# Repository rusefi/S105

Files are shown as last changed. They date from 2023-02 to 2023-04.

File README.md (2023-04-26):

# S105

Reverse engineering of SOATE S105 396200-3763010-00 ECU using KiCad EDA

[TL,DR: schematics (see open issues)](hardware/s105/s105.pdf)

[Interactive Pinout](https://rusefi.com/docs/pinouts/s105/)

Geehy apm32F407VGT7

[Forum Discussion](https://rusefi.com/forum/viewtopic.php?f=4&t=2496)

x



https://www.youtube.com/watch?v=v7S3eSeuTio

Alternative unofficial firmware https://github.com/rusefi/rusefi/tree/master/firmware/config/boards/s105

Binary https://rusefi.com/build_server/rusefi_bundle_s105.zip

See also https://github.com/rusefi/m74.9

[rusefi-status.md](rusefi-status.md)

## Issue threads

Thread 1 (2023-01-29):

источники

rusefillc, 2023-01-29:
В проекте уже есть две маленькие подсхемы https://github.com/rusefi/S105/tree/main/hardware/s105

Главный разъём предлагаю взять из районов https://github.com/rusefi/hellen121vag - на S105 на самом деле 81 пиновая варианция, но мы проигнорируем это различие. @Nadezhda-n подключу библиотеку, какую скажешь.

распиновка главного разъёма https://rusefi.com/docs/pinouts/s105/

100pin stm32 символ и типичная обвязка вокруг https://github.com/rusefi/hw_microRusEfi/

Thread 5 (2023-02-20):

VR

rusefillc, 2023-02-20:
VR A1 требует уточнения. Q19, наверно, диодная сборка. А R247-251 и R252-253 требует уточнения подключения

Nadezhda-n, 2023-02-21:
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
Одно уточнение, действительно, появилось

rusefillc, 2023-05-01:
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

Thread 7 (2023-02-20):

OD 2A14

rusefillc, 2023-02-20:
Схема OD 2A14 требует уточнения. Не подключен силовой транзистор. Непонятно как он управляется. Предположительно перепутана полярность маленьких диодов. Контакт разъема 13  это не выход, а вход.

Nadezhda-n, 2023-02-21:
Честно говоря, я не следила за полярностью маленьких диодов - мне не очень видно :)

Nadezhda-n, 2023-02-21:
> Схема OD 2A14 требует уточнения. Не подключен силовой транзистор. Непонятно как он управляется. Предположительно перепутана полярность маленьких диодов. Контакт разъема 13 это не выход, а вход.

Если ты про D15, то я и прозвонкой не нашла, и дорожки от него не видно, и отверстия нет (на другой стороне), так что я тут даже и не знаю...

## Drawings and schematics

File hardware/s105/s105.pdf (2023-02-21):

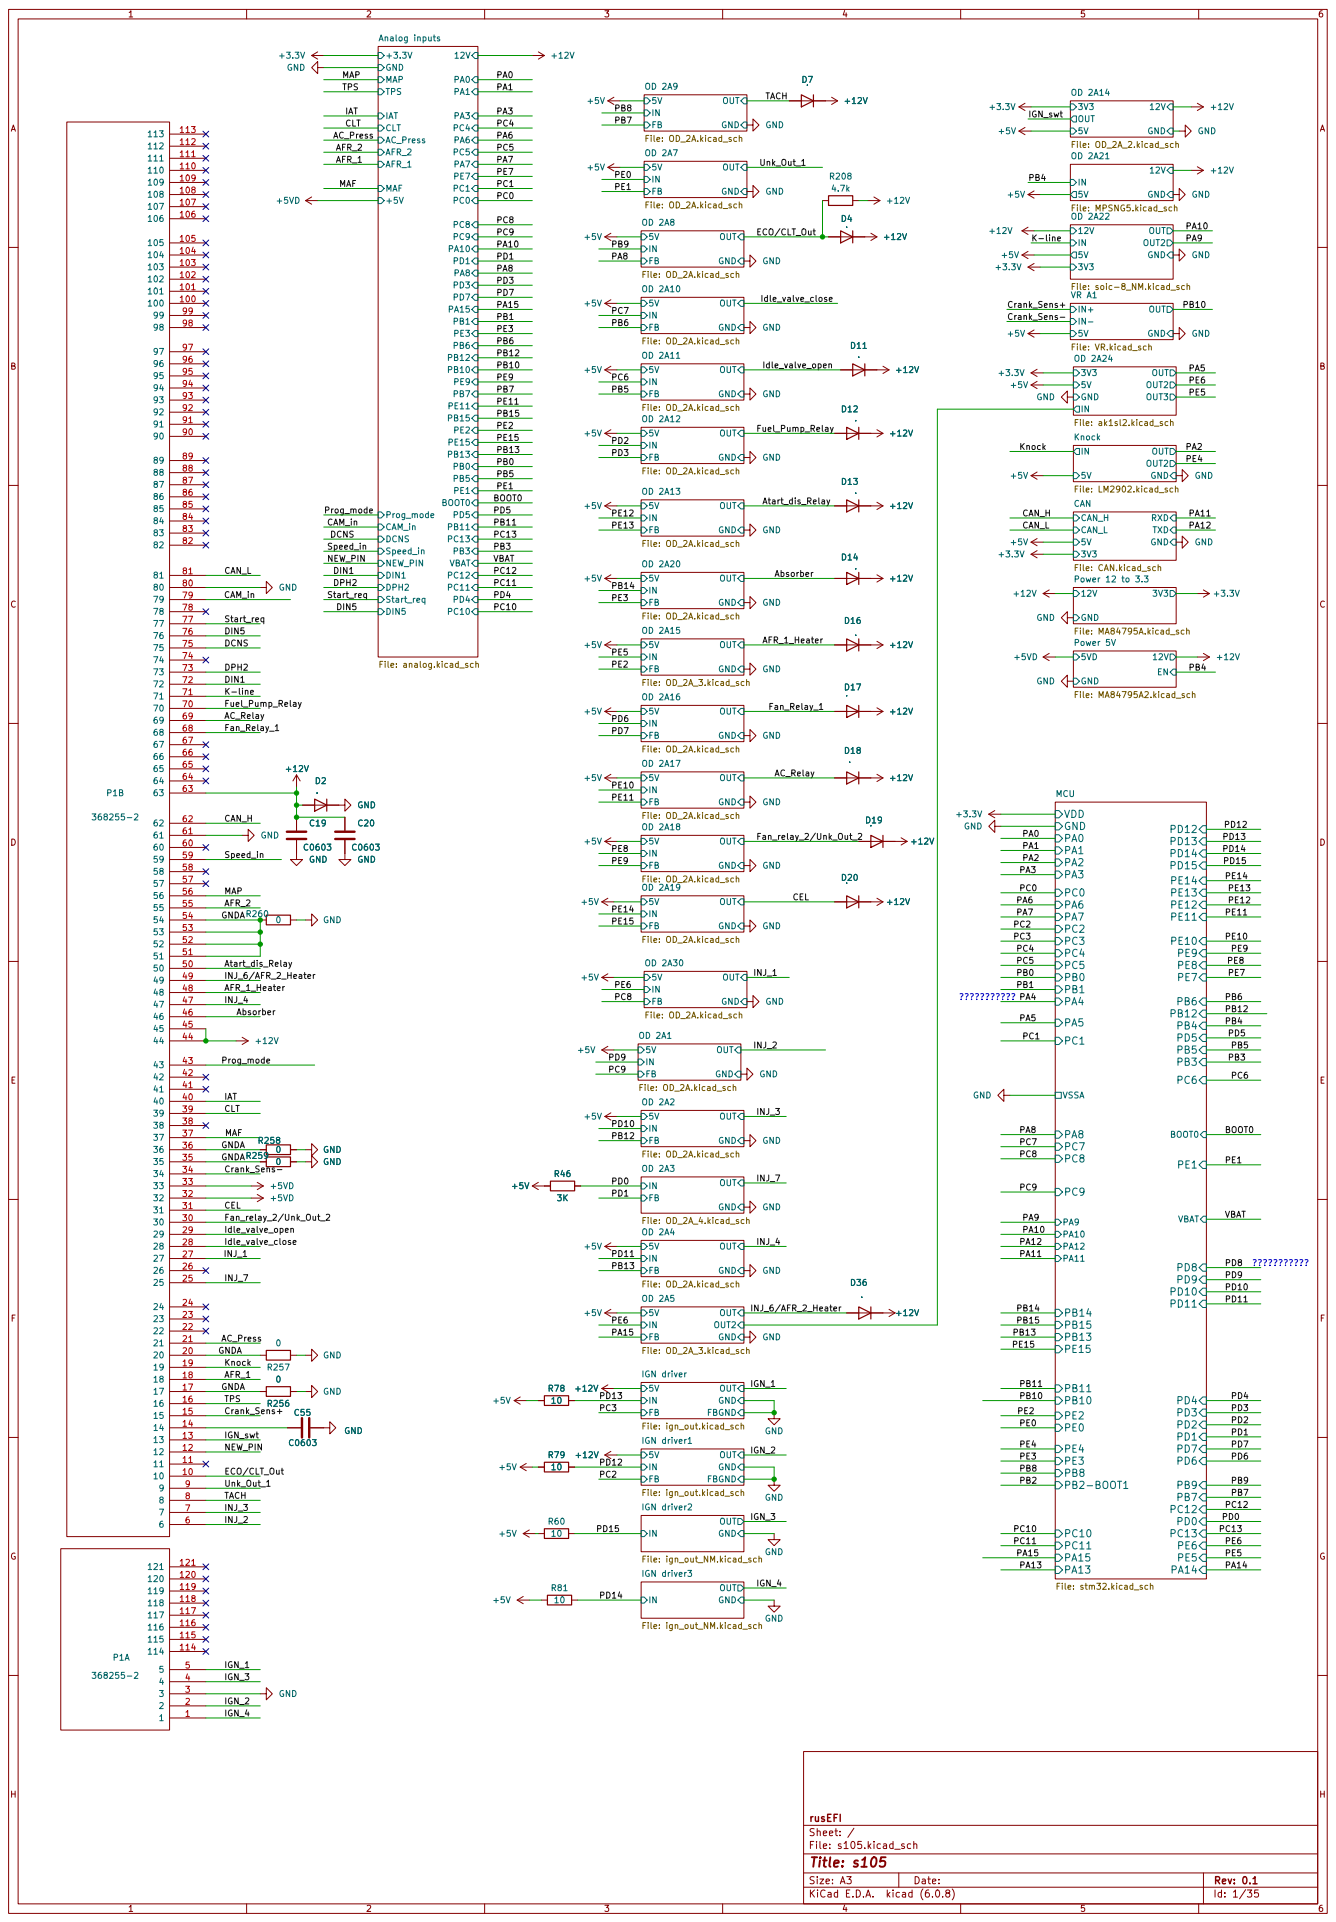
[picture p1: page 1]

3V3 OD 2A22 File: soic-8_NM.kicad_sch OUT

IN- VR A1 File: VR.kicad_sch

3V3 Power 12 to 3.3 File: MA84795A.kicad_sch OUT
GND

File: s105.kicad_sch Sheet: / rusEFI OUT

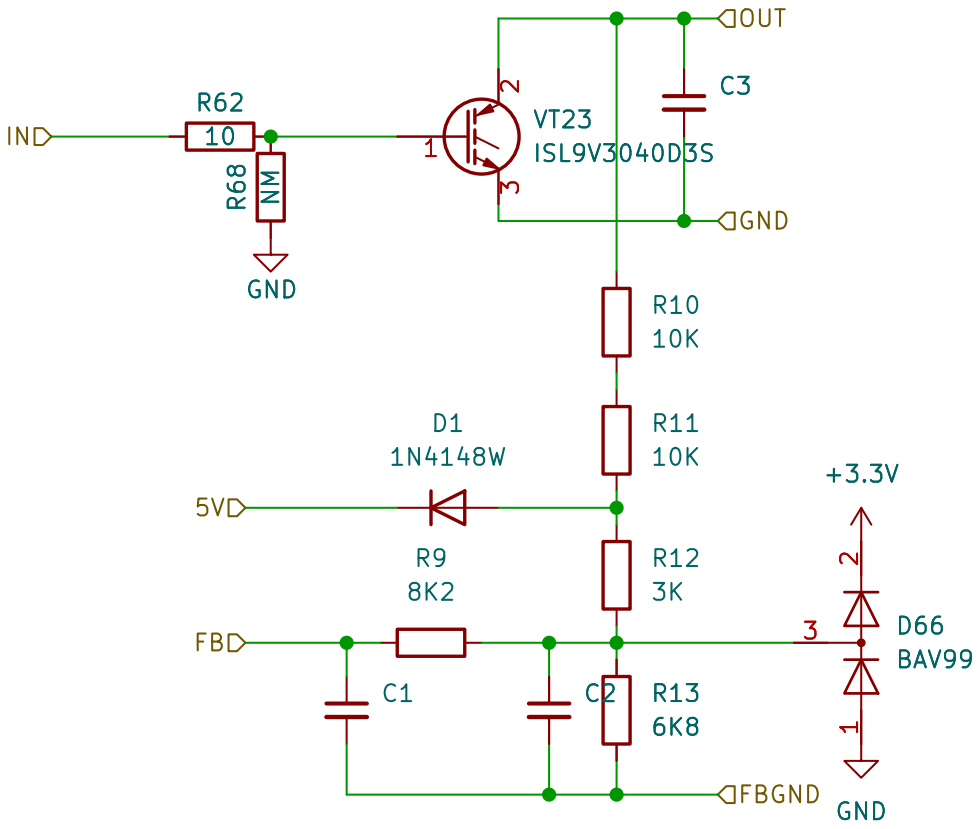
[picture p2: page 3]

File: ign_out.kicad_sch Sheet: /IGN driver/ rusEFI

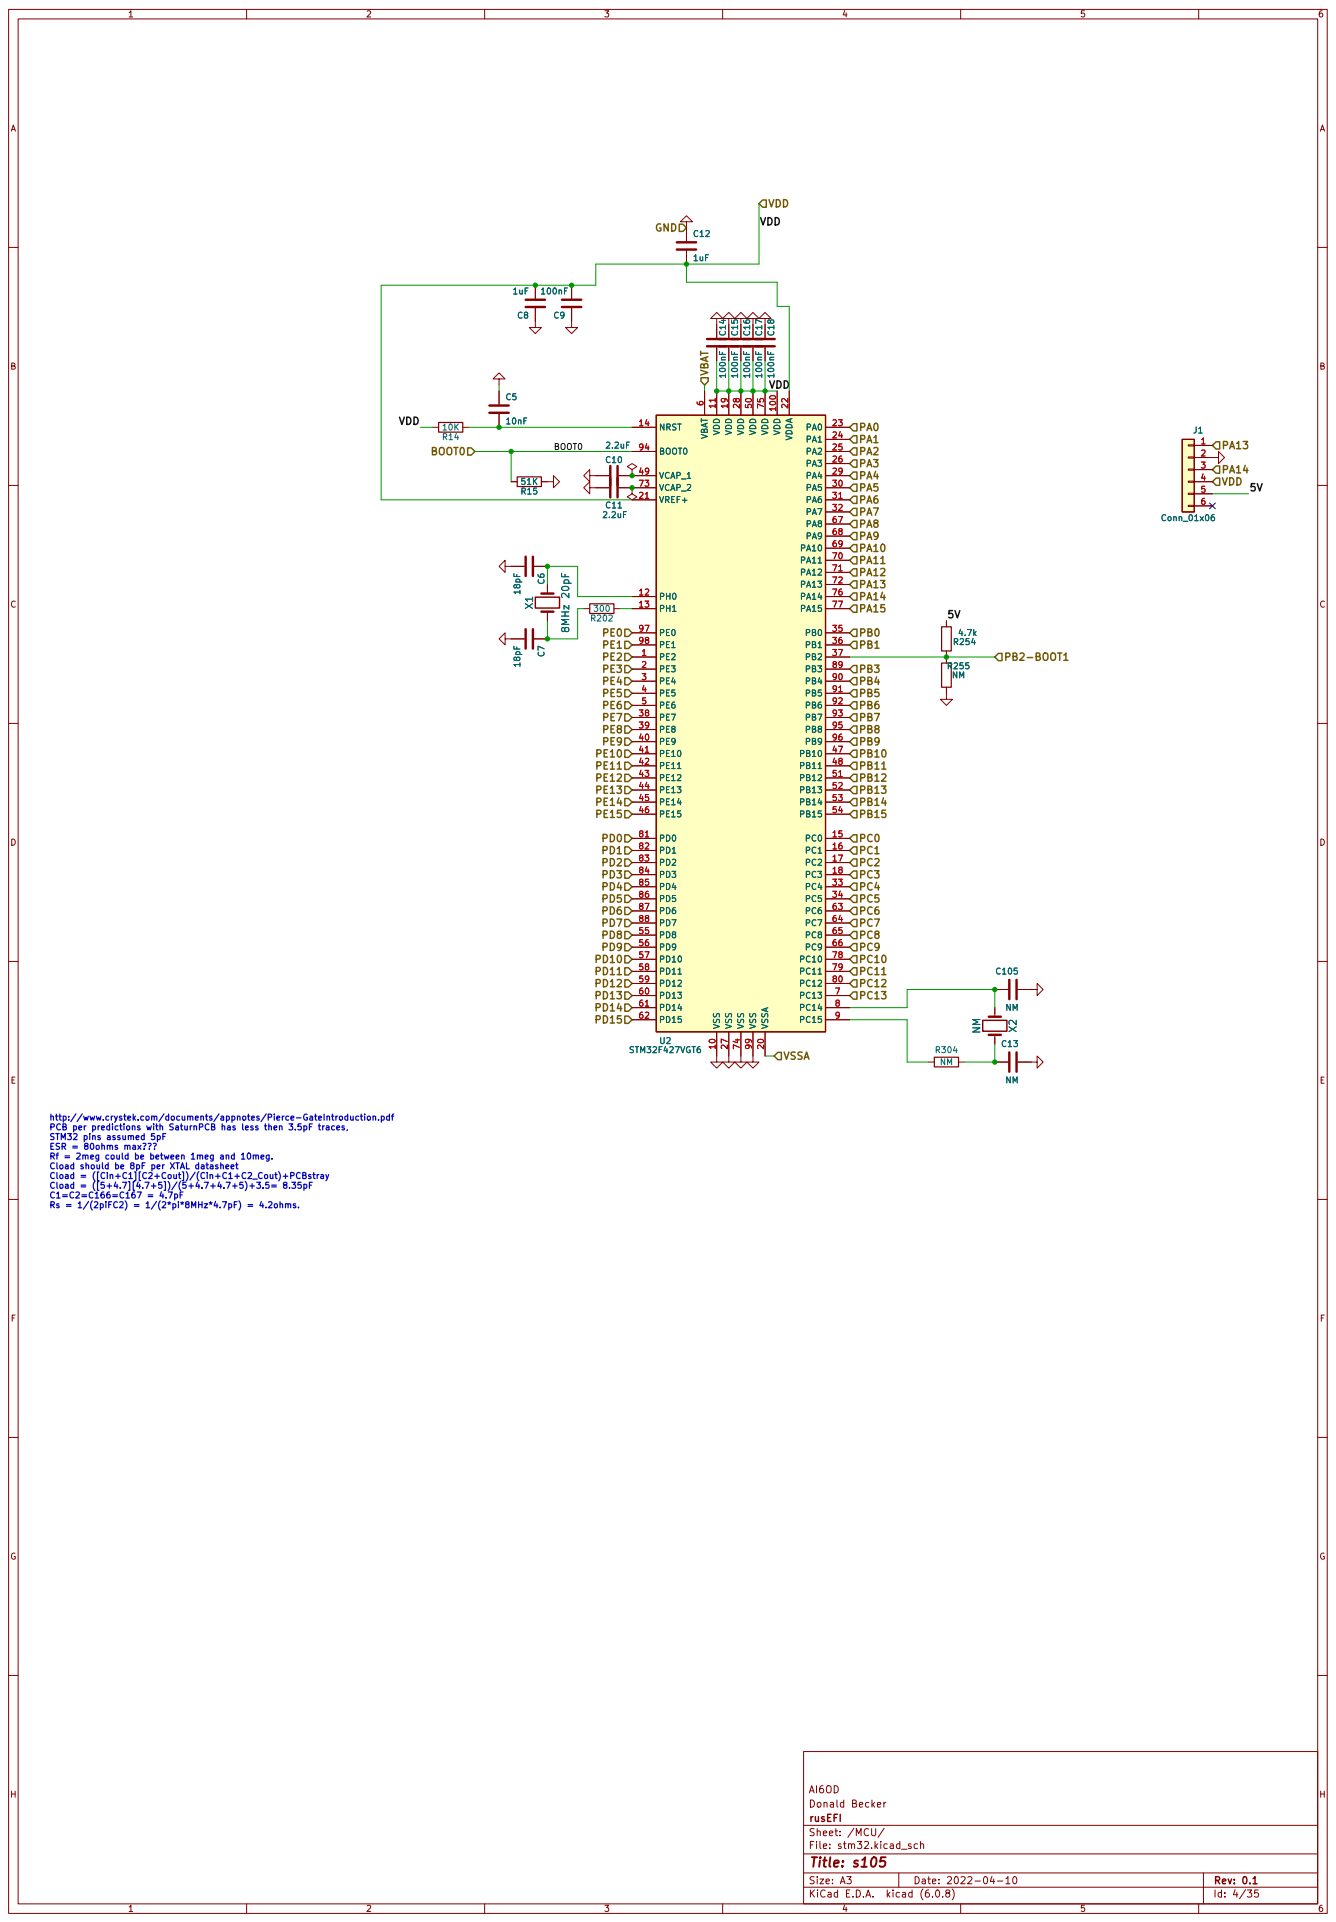
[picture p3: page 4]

http://www.crystek.com/documents/appnotes/Pierce-GateIntroduction.pdf
PCB per predictions with SaturnPCB has less then 3.5pF traces,
STM32 pins assumed 5pF ESR = 80ohms max??? Rf = 2meg could be between 1meg and 10meg.

Cload should be 8pF per XTAL datasheet
Cload = ([Cin+C1][C2+Cout])/(Cin+C1+C2_Cout)+PCBstray
Cload = ([5+4.7][4.7+5])/(5+4.7+4.7+5)+3.5= 8.35pF

File: stm32.kicad_sch Sheet: /MCU/ rusEFI Donald Becker AI6OD

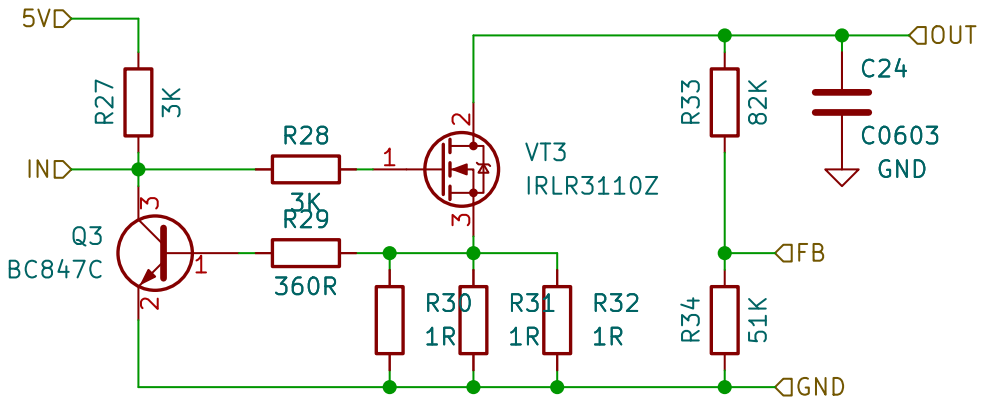
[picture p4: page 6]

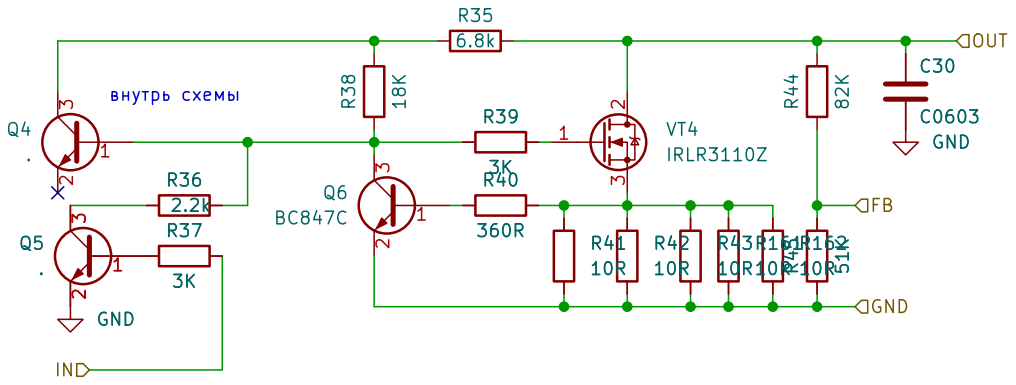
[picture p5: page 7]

File: OD_2A_4.kicad_sch Sheet: /OD 2A3/ rusEFI

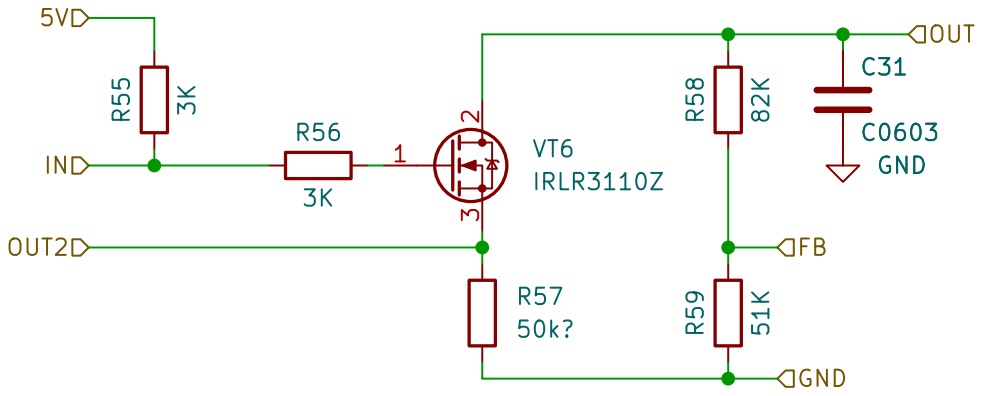
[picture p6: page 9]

File: OD_2A_3.kicad_sch Sheet: /OD 2A5/ rusEFI

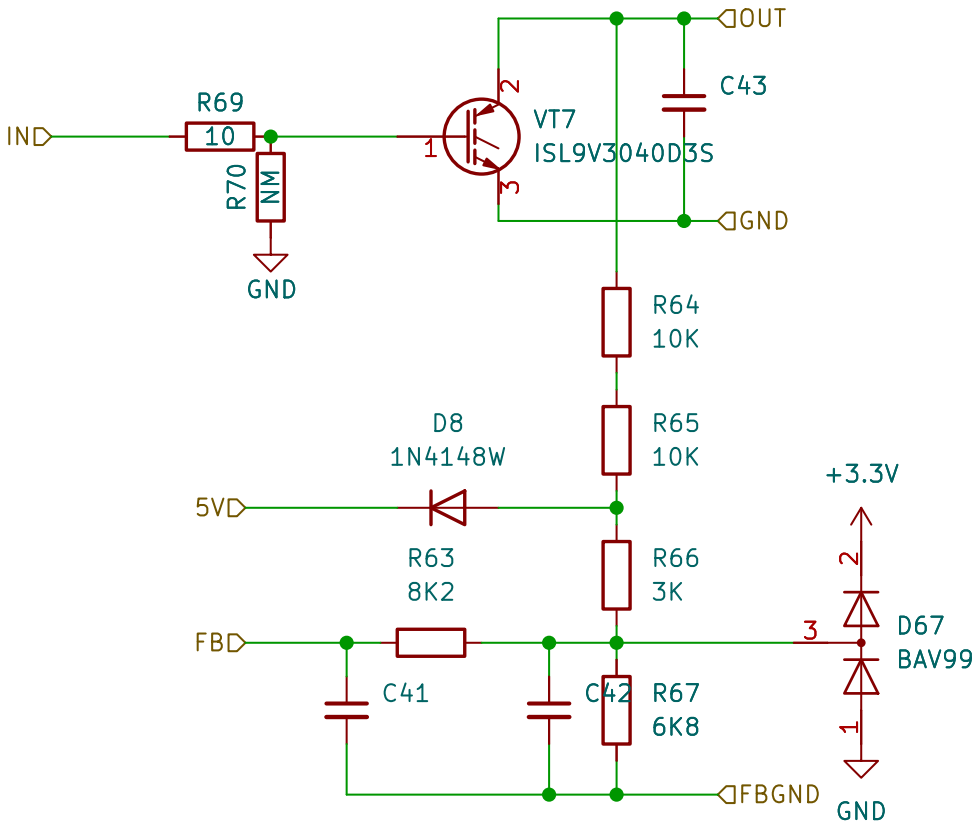
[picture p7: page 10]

File: ign_out.kicad_sch Sheet: /IGN driver1/ rusEFI

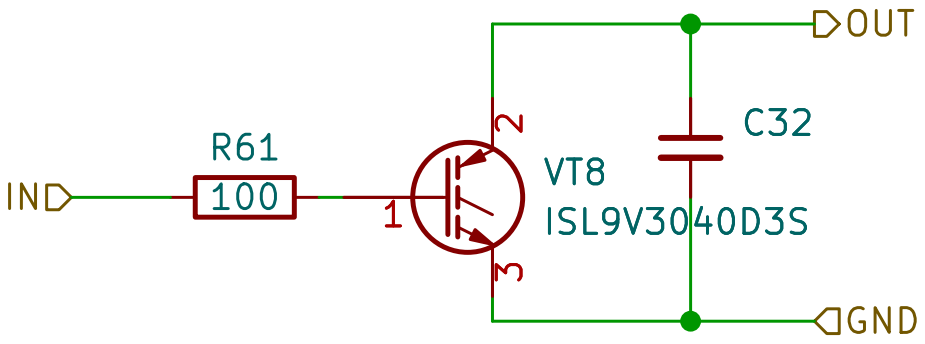
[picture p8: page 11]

File: ign_out_NM.kicad_sch Sheet: /IGN driver2/ rusEFI

File: ign_out_NM.kicad_sch Sheet: /IGN driver3/ rusEFI

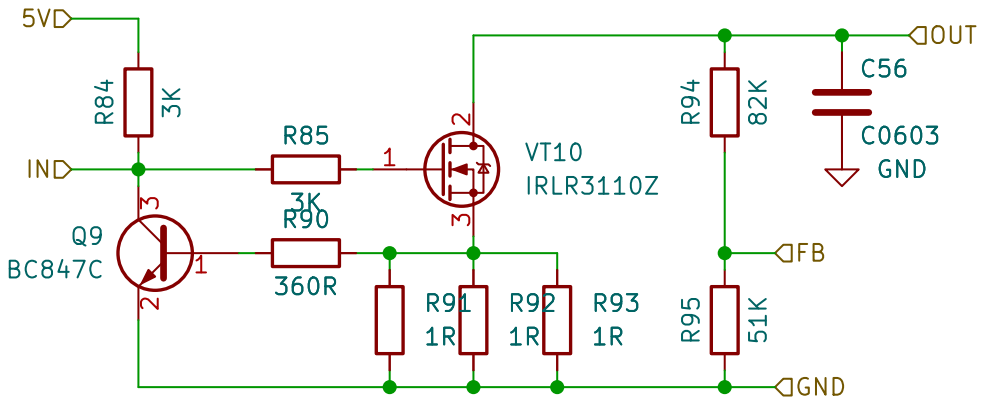
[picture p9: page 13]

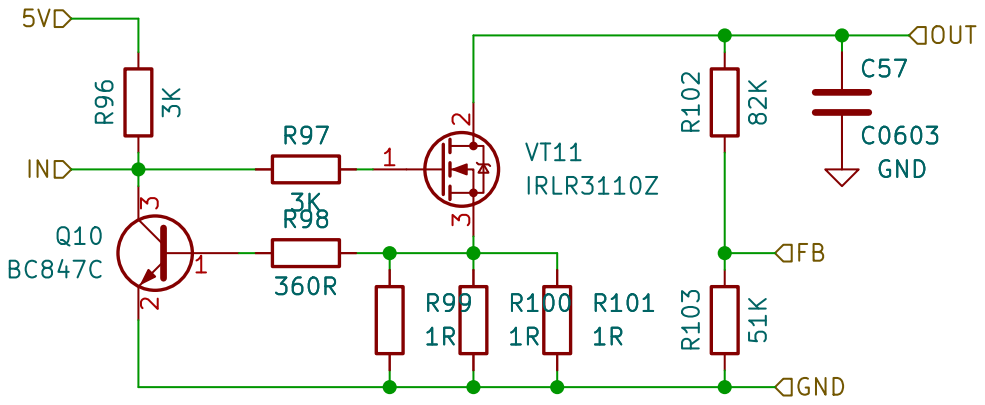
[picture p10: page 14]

File: OD_2A.kicad_sch Sheet: /OD 2A9/ rusEFI

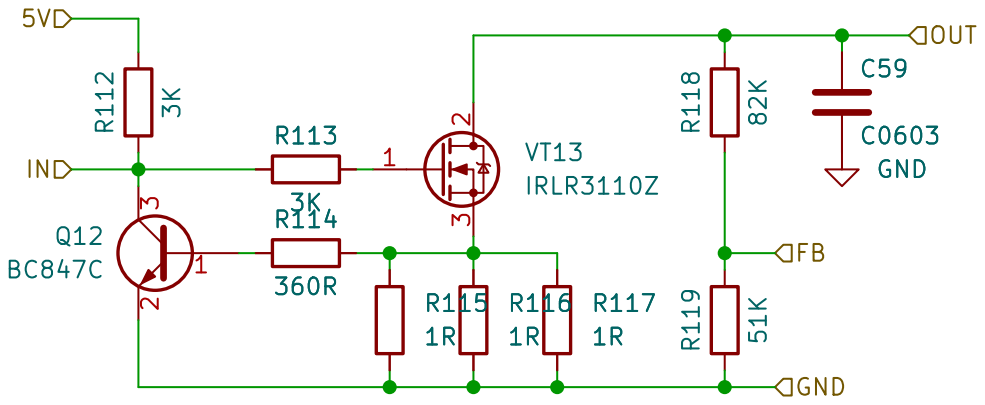
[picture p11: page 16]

File: OD_2A.kicad_sch Sheet: /OD 2A10/ rusEFI

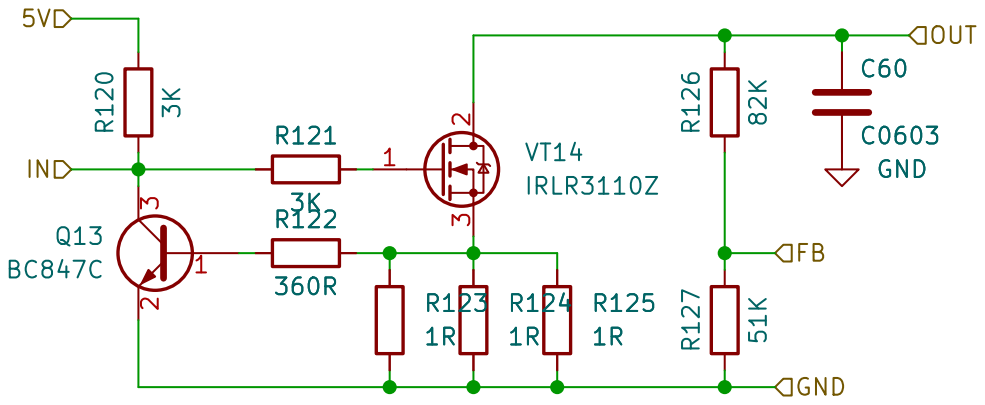
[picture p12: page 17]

File: OD_2A.kicad_sch Sheet: /OD 2A11/ rusEFI

File: OD_2A.kicad_sch Sheet: /OD 2A12/ rusEFI


File: OD_2A.kicad_sch Sheet: /OD 2A13/ rusEFI


File: OD_2A.kicad_sch Sheet: /OD 2A20/ rusEFI

File: OD_2A_3.kicad_sch Sheet: /OD 2A15/ rusEFI


File: OD_2A.kicad_sch Sheet: /OD 2A16/ rusEFI


File: OD_2A.kicad_sch Sheet: /OD 2A17/ rusEFI

File: OD_2A.kicad_sch Sheet: /OD 2A18/ rusEFI


File: OD_2A.kicad_sch Sheet: /OD 2A19/ rusEFI


File: OD_2A_2.kicad_sch Sheet: /OD 2A14/ rusEFI


File: MPSNG5.kicad_sch Sheet: /OD 2A21/ rusEFI

Sheet: /Analog inputs/ rusEFI Donald Becker AI6OD


File: soic-8_NM.kicad_sch Sheet: /OD 2A22/ rusEFI


File: LM2902.kicad_sch Sheet: /Knock/ rusEFI

File: ak1sl2.kicad_sch Sheet: /OD 2A24/ rusEFI


File: VR.kicad_sch Sheet: /VR A1/ rusEFI


3 RXD 4 VREF 5 CANL 6 CANH 7 S

File: CAN.kicad_sch Sheet: /CAN/ rusEFI

File: MA84795A.kicad_sch Sheet: /Power 12 to 3.3/ rusEFI


File: MA84795A2.kicad_sch Sheet: /Power 5V/ rusEFI

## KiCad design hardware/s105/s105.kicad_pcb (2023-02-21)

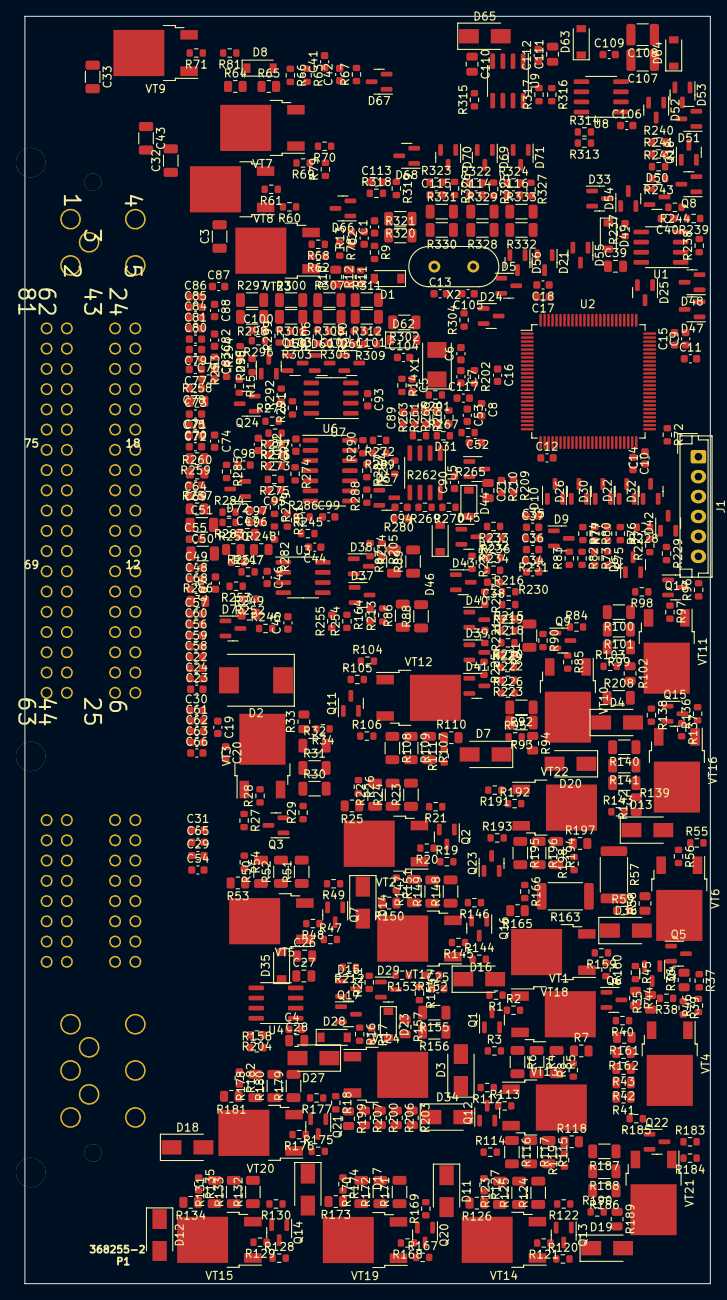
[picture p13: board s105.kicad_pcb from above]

Board: 2 copper layers, 86.0 x 159.0 mm, 583 parts (0 on the bottom side), 262 nets, no tracks yet.

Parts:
C1, C2, C41, C42: C_0603_1608Metric
C3, C32, C33, C43: C_Small; C_1206_3216Metric
C4, C19, C20, C22, C23, C24, C25, C29, C30, C31, C40, C44, C45, C46, C49, C54, C55, C56, C57, C58, C59, C60, C61, C62, C63, C64, C65, C66, C67, C68, C70, C71, C84, C85, C86, C87, C89, C90, C91, C92, C93, C94, C95, C96, C97, C98, C99, C100, C106, C109, C112: C0603; C_0603_1608Metric
C5: 10nF; C_0603_1608Metric
C6, C7: 18pF; C_0603_1608Metric
C8, C12: 1uF; C_0603_1608Metric
C9, C14, C15, C16, C17, C18, C34, C35, C36, C37, C38, C48, C52, C53, C69, C72, C73, C74, C75, C76, C77, C78, C79, C80, C81, C82, C83, C88, C101, C104, C113, C114, C115, C116, C117: 100nF; C_0603_1608Metric
C10, C11: 2.2uF; C_0603_1608Metric
C13, C102, C103, C105: NM; C_0603_1608Metric
C21, C26, C27, C28, C39, C47, C110, C111: C0805; C_0805_2012Metric
C50, C51: C1206; C_1206_3216Metric
C107, C108: C1210; C_1210_3225Metric
D1, D8, D23, D28, D44, D46: 1N4148W; D_SOD-123
D2: .; D_SMC
D3: NM; D_SMA
D4, D7, D11, D12, D13, D14, D16, D17, D18, D19, D20, D27, D34, D36, D65: .; D_SMA
D5, D6, D9, D10, D15, D21, D22, D24, D25, D26, D29, D30, D31, D32, D33, D37, D38, D39, D40, D41, D42, D43, D45, D47, D48, D50, D51, D52, D53, D54, D55, D56, D57, D58, D59, D60, D61, D66, D67, D68, D69, D70, D71, D72: BAV99; SOT-23
D35, D49, D63, D64: .; D_SOD-123
D62: NM; D_SOD-123
D73: .; SOT-23
J1: Conn_01x06; JST_EH_B6B-EH-A_1x06_P2.50mm_Vertical
P1: 368255-2
Q1, Q2, Q3, Q6, Q7, Q8, Q9, Q10, Q11, Q12, Q13, Q14, Q15, Q16, Q17, Q18, Q20, Q21, Q22, Q23: BC847C; SOT-23
Q4, Q5, Q24: .; SOT-23
R1, R2, R12, R16, R17, R19, R20, R27, R28, R37, R39, R46, R47, R48, R55, R56, R66, R84, R85, R96, R97, R104, R105, R112, R113, R120, R121, R128, R129, R136, R137, R144, R145, R159, R160, R167, R168, R175, R176, R183, R184, R191, R192: 3K; R_0603_1608Metric
R3, R18, R21, R29, R40, R49, R90, R98, R106, R114, R122, R130, R138, R146, R169, R177, R185, R193: 360R; R_0603_1608Metric
R4, R5, R6, R22, R23, R24, R30, R31, R32, R50, R51, R52, R91, R92, R93, R99, R100, R101, R107, R108, R109, R115, R116, R117, R123, R124, R125, R131, R132, R133, R139, R140, R141, R147, R148, R149, R170, R171, R172, R178, R179, R180, R186, R187, R188, R194, R195, R196: 1R; R_1206_3216Metric
R7, R25, R33, R44, R53, R58, R94, R102, R110, R118, R126, R134, R142, R150, R165, R173, R181, R189, R197: 82K; R_0805_2012Metric
R8, R15, R26, R34, R45, R54, R59, R95, R103, R111, R119, R127, R135, R143, R151, R166, R174, R182, R190, R198: 51K; R_0603_1608Metric
R9, R63: 8K2; R_0603_1608Metric
R10, R11, R64, R65: 10K; R_0805_2012Metric
R13, R67: 6K8; R_0603_1608Metric
R14: 10K; R_0603_1608Metric
R35: 6.8k; R_0805_2012Metric
R36: 2.2k; R_0805_2012Metric
R38: 18K; R_0603_1608Metric
R41, R42, R43, R161, R162, R199, R200, R203, R206, R207: 10R; R_0805_2012Metric
R57, R163: 50k?; R_2512_6332Metric
R60, R62, R69, R78, R79, R81: 10; R_0603_1608Metric
R61, R71, R80, R153, R204, R233, R236: 100; R_0603_1608Metric
R68, R70, R73, R74, R75, R82, R83, R212, R216, R219, R223, R224, R225, R226, R227, R228, R229, R232, R234, R235, R238, R255, R261, R293, R299, R304, R306, R313, R314, R326: NM; R_0603_1608Metric
R72, R211, R215, R220, R269, R272, R273, R276, R278, R279, R317: 1k; R_0603_1608Metric
R76: 22K; R_0603_1608Metric
R77: 510K; R_0603_1608Metric
R86, R87, R88, R89: 3k; R_1206_3216Metric
R152, R210: 6.8k; R_0603_1608Metric
R154, R209: 68k; R_0603_1608Metric
R155, R156, R208, R298, R311, R320, R329, R332: 4.7k; R_1206_3216Metric
R157, R248, R249, R250: 10k; R_0805_2012Metric
R158, R239, R245, R247, R251, R252, R253, R254, R295, R315, R316: 4.7k; R_0603_1608Metric
R164, R205, R213, R214, R217, R221, R237, R274, R275, R277, R285, R286, R287, R288, R289, R290: 22k; R_0603_1608Metric
R201, R230, R231, R263: 3k; R_0603_1608Metric
R202, R264, R280, R283, R303, R305, R323: 300; R_0603_1608Metric
R218, R222, R271: 6k; R_0603_1608Metric
R240, R241: 47; R_0603_1608Metric
R242, R284, R294, R310, R319, R325, R327: 51k; R_0603_1608Metric
R243, R244, R296, R309, R318, R322, R324: 33k; R_0603_1608Metric
R246: 82k; R_0603_1608Metric
R256, R257, R258, R259, R260: 0; R_0805_2012Metric
R262, R265, R266, R267, R268, R270: MN; R_0603_1608Metric
R281, R282: 18k; R_0603_1608Metric
R291, R292: 62; R_0603_1608Metric
R297, R300, R301, R302, R307, R308, R312, R321, R328, R330, R331, R333: NM; R_1206_3216Metric
U1, U4, U5, U8, U9: case only; SOIC-8_3.9x4.9mm_P1.27mm
U2: STM32F427VGT6; LQFP-100_14x14mm_P0.5mm
U3: LM2903; SOIC-8_3.9x4.9mm_P1.27mm
U6: LM2902; SO-14_3.9x8.65mm_P1.27mm
U7: SIT1042T/3; SOIC-8_3.9x4.9mm_P1.27mm
VT1, VT2, VT3, VT4, VT5, VT6, VT10, VT11, VT12, VT13, VT14, VT15, VT16, VT17, VT18, VT19, VT20, VT21, VT22, VT24: IRLR3110Z; TO-252-2
VT7, VT8, VT9, VT23: ISL9V3040D3S; TO-252-2
X1: 8MHz 20pF; Crystal_SMD_5032-2Pin_5.0x3.2mm
X2: NM; Crystal_HC49-U_Vertical

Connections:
+3.3V: C8.2, C9.2, C12.2, C14.2, C15.2, C16.2, C17.2, C18.2, C106.1, C107.1, C108.1, D5.2 (A), D6.2 (A), D9.2 (A), D10.2 (A), D21.2 (A), D22.2 (A), D24.2 (A), D25.2 (A), D26.2 (A), D29.2 (A), D30.2 (A), D31.2 (A), D32.2 (A), D33.2 (A), D37.2 (A), D38.2 (A), D39.2 (A), D40.2 (A), D41.2 (A), D42.2 (A), D43.2 (A), D44.1 (K), D45.2 (A), D46.1 (K), D47.2 (A), D48.2 (A), D50.2 (A), D51.2 (A), D52.2 (A), D53.2 (A), D54.2 (A), D55.2 (A), D56.2 (A), D58.2 (A), D59.2 (A), D60.2 (A), D61.2 (A), D64.1 (K), D66.2 (A), D67.2 (A), D68.2 (A), D69.2 (A), D70.2 (A), D71.2 (A), J1.4, R14.1, R86.2, R87.1, R88.2, R89.1, R229.2, R244.2, R265.1, R270.1, R313.1, U2.11 (VDD), U2.19 (VDD), U2.21 (VREF+), U2.22 (VDDA), U2.28 (VDD), U2.50 (VDD), U2.75 (VDD), U2.100 (VDD), U7.5 (VREF), U8.1 (BOOT)
+5V: C4.1, C28.1, C40.1, C44.1, C90.1, C93.1, D27.2 (A), D72.2 (A), R1.2, R19.2, R27.2, R46.1, R47.2, R55.2, R60.1, R78.1, R79.1, R81.1, R84.2, R96.2, R104.2, R112.2, R120.2, R128.2, R136.2, R144.2, R154.2, R155.2, R156.2, R157.2, R158.2, R159.2, R167.2, R175.2, R183.2, R191.2, R238.2, R245.2, R251.1, R271.2, R274.1, U1.3 (GND), U3.8 (V+), U4.1 (BOOT), U5.8 (PHASE), U6.4 (V+), U7.3 (VCC)
+5VD: C87.1, C111.1, C112.1, P1.32, P1.33, R74.1, R80.1, R216.2, R219.2, R224.2, R232.2, R236.1, R316.1, U9.1 (BOOT)
+12V: C19.1, C20.1, C26.1, C39.1, D1.1 (K), D2.2 (A), D3.2 (A), D4.1 (K), D7.1 (K), D8.1 (K), D11.1 (K), D12.1 (K), D13.1 (K), D14.1 (K), D16.1 (K), D17.1 (K), D18.1 (K), D19.1 (K), D20.1 (K), D35.2 (A), D36.1 (K), D49.2 (A), D63.2 (A), D65.2 (A), P1.44, P1.45, P1.63, R208.1, R297.2, R300.2, R307.2, R311.2, R320.2, R328.2, R330.2, R332.2, U1.7 (COMP/DIS/OC)
/AC_Press: C76.2, P1.21, R223.2, R224.1, R225.1
/AC_Relay: C66.1, D18.2 (A), P1.69, R181.2, VT20.2 (D)
/AFR_1: C70.1, P1.18, R76.1, R77.2, R228.2
/AFR_1_Heater: C29.1, D16.2 (A), P1.48, R165.2, VT18.2 (D)
/AFR_2: C64.1, P1.55, R82.2, R83.1, R227.1
/Absorber: C63.1, D14.2 (A), P1.46, R150.2, VT17.2 (D)
/Atart_dis_Relay: C62.1, D13.2 (A), P1.50, R142.2, VT16.2 (D)
/BOOT0: R15.1, R293.1, U2.94 (BOOT0)
/CAM_in: C88.2, P1.79, R299.2, R300.1, R301.2
/CAN_H: C84.1, P1.62, Q24.1 (B), R291.1, U7.7 (CANH)
/CAN_L: C85.1, P1.81, Q24.2 (E), R292.2, U7.6 (CANL)
/CEL: C68.1, D20.2 (A), P1.31, R197.2, VT22.2 (D)
/CLT: C75.2, P1.39, R87.2, R89.2, R205.1, R214.1
/Crank_Sens+: C47.1, C51.1, P1.15, R249.1, R250.1
/Crank_Sens-: C47.2, C50.1, P1.34, R248.1, R250.2
/DCNS: C73.2, P1.75, R306.2, R307.1, R308.2
/DIN1: C80.2, P1.72, R319.2, R320.1, R321.2
/DIN5: C83.2, P1.76, R327.2, R332.1, R333.2
/DPH2: C81.2, P1.73, R326.2, R330.1, R331.2
/ECO/CLT_Out: C57.1, D4.2 (A), P1.10, R102.2, R208.2, VT11.2 (D)
/Fan_Relay_1: C65.1, D17.2 (A), P1.68, R173.2, VT19.2 (D)
/Fan_relay_2/Unk_Out_2: C67.1, D19.2 (A), P1.30, R189.2, VT21.2 (D)
/Fuel_Pump_Relay: C61.1, D12.2 (A), P1.70, R134.2, VT15.2 (D)
/GNDA: P1.17, P1.20, P1.35, P1.36, P1.51, P1.52, P1.53, P1.54, R256.1, R257.1, R258.1, R259.1, R260.1
/IAT: C77.2, P1.40, R86.1, R88.1, R164.1, R213.1
/IGN_1: C3.1, P1.5, R10.1, VT23.2 (C)
/IGN_2: C43.1, P1.2, R64.1, VT7.2 (C)
/IGN_3: C32.1, P1.4, VT8.2 (C)
/IGN_4: C33.1, P1.1, VT9.2 (C)
/IGN_swt: C49.1, D28.1 (K), P1.13
/INJ_1: C22.1, P1.27, R7.2, VT1.2 (D)
/INJ_2: C23.1, P1.6, R25.2, VT2.2 (D)
/INJ_3: C24.1, P1.7, R33.2, VT3.2 (D)
/INJ_4: C54.1, P1.47, R53.2, VT5.2 (D)
/INJ_6/AFR_2_Heater: C31.1, D36.2 (A), P1.49, R58.2, VT6.2 (D)
/INJ_7: C30.1, P1.25, R35.1, R44.2, VT4.2 (D)
/Idle_valve_close: C59.1, P1.28, R118.2, VT13.2 (D)
/Idle_valve_open: C60.1, D11.2 (A), P1.29, R126.2, VT14.2 (D)
/K-line: C86.1, P1.71, R237.1, R240.1, R241.1, R242.1, U1.6 (FB)
/Knock: C71.1, C98.2, P1.19
/MAF: C72.2, P1.37, R232.1, R234.1, R235.1
/MAP: C74.2, P1.56, R215.2, R216.1, R217.1
/MCU/5V: J1.5, R254.1
/NEW_PIN: C48.2, P1.12, R302.2
/OD 2A15/OUT2: R163.1, VT18.3 (S)
/OD 2A24/IN: R57.1, R268.2, VT6.3 (S)
/PA0: C53.2, D40.3 (K), R217.2, R218.2, U2.23 (PA0)
/PA1: C52.2, D39.3 (K), R221.2, R222.2, U2.24 (PA1)
/PA2: C92.1, D46.2 (A), R278.1, U2.25 (PA2)
/PA3: C36.2, D38.3 (K), R214.2, U2.26 (PA3)
/PA5: C89.1, R261.1, R262.2, R263.1, R264.2, U2.30 (PA5)
/PA6: D41.3 (K), R225.2, R226.1, R231.1, U2.31 (PA6)
/PA7: C37.2, D6.3 (K), R76.2, U2.32 (PA7)
/PA8: D53.3 (K), R102.1, R103.2, U2.67 (PA8)
/PA9: R239.2, U1.4 (LGATE), U2.68 (PA9)
/PA10: D50.3 (K), R242.2, R243.1, U1.1 (BOOT), U2.69 (PA10)
/PA11: U2.70 (PA11), U7.4 (RXD)
/PA12: U2.71 (PA12), U7.1 (TXD)
/PA13: J1.1, U2.72 (PA13)
/PA14: J1.3, U2.76 (PA14)
/PA15: D25.3 (K), R58.1, R59.2, U2.77 (PA15)
/PB0: C34.2, U2.35 (PB0)
/PB1: C21.1, D31.3 (K), R209.1, R210.1, U2.36 (PB1)
/PB2: R254.2, R255.1, U2.37 (PB2)
/PB3: C101.2, D61.3 (K), R309.2, R310.1, U2.89 (PB3)
/PB4: R315.1, U2.90 (PB4), U4.5 (VCC), U9.5 (VCC)
/PB5: D55.3 (K), R126.1, R127.2, U2.91 (PB5)
/PB6: D33.3 (K), R118.1, R119.2, U2.92 (PB6)
/PB7: D21.3 (K), R110.1, R111.2, U2.93 (PB7)
/PB8: Q11.3 (C), R104.1, R105.1, U2.95 (PB8)
/PB9: Q10.3 (C), R96.1, R97.1, U2.96 (PB9)
/PB10: D30.3 (K), U2.47 (PB10), U3.1
/PB11: C103.2, D59.3 (K), R299.1, R303.2, U2.48 (PB11)
/PB12: D32.3 (K), R33.1, R34.2, U2.51 (PB12)
/PB13: D42.3 (K), R53.1, R54.2, U2.52 (PB13)
/PB14: Q16.3 (C), R144.1, R145.1, U2.53 (PB14)
/PB15: R72.1, U2.54 (PB15)
/PC0: C117.2, D44.2 (A), D45.3 (K), R233.2, R236.2, U2.15 (PC0)
/PC1: C38.2, D43.3 (K), R201.1, R235.2, U2.16 (PC1)
/PC2: C41.1, R63.1, U2.17 (PC2)
/PC3: C1.1, R9.1, U2.18 (PC3)
/PC4: C35.2, D37.3 (K), R164.2, U2.33 (PC4)
/PC5: D9.3 (K), R83.2, R230.1, U2.34 (PC5)
/PC6: Q13.3 (C), R120.1, R121.1, U2.63 (PC6)
/PC7: Q12.3 (C), R112.1, R113.1, U2.64 (PC7)
/PC8: D47.3 (K), R7.1, R8.2, U2.65 (PC8)
/PC9: D48.3 (K), R25.1, R26.2, U2.66 (PC9)
/PC10: C116.2, D71.3 (K), R324.2, R327.1, U2.78 (PC10)
/PC11: C115.2, D70.3 (K), R323.2, R326.1, U2.79 (PC11)
/PC12: C113.2, D68.3 (K), R318.2, R319.1, U2.80 (PC12)
/PC13: C102.2, D60.3 (K), R305.2, R306.1, U2.7 (PC13)
/PD0: R37.2, R46.2, U2.81 (PD0)
/PD1: D51.3 (K), R44.1, R45.2, U2.82 (PD1)
/PD2: Q14.3 (C), R128.1, R129.1, U2.83 (PD2)
/PD3: D52.3 (K), R134.1, R135.2, U2.84 (PD3)
/PD4: C114.2, D69.3 (K), R322.2, R325.1, U2.85 (PD4)
/PD5: R295.1, U2.86 (PD5)
/PD6: Q20.3 (C), R167.1, R168.1, U2.87 (PD6)
/PD7: D54.3 (K), R173.1, R174.2, U2.88 (PD7)
/PD9: Q2.3 (C), R19.1, R20.1, U2.56 (PD9)
/PD10: Q3.3 (C), R27.1, R28.1, U2.57 (PD10)
/PD11: Q7.3 (C), R47.1, R48.1, U2.58 (PD11)
/PD12: R69.1, R79.2, U2.59 (PD12)
/PD13: R62.1, R78.2, U2.60 (PD13)
/PD14: R71.1, R81.2, U2.61 (PD14)
/PD15: R60.2, R61.1, U2.62 (PD15)
/PE0: Q9.3 (C), R84.1, R85.1, U2.97 (PE0)
/PE1: D56.3 (K), R94.1, R95.2, U2.98 (PE1)
/PE2: D5.3 (K), R165.1, R166.2, U2.1 (PE2)
/PE3: D24.3 (K), R150.1, R151.2, U2.2 (PE3)
/PE4: D72.3 (K), R284.1, R285.2, U2.3 (PE4)
/PE5: R159.1, R160.1, R269.1, R270.2, U2.4 (PE5), U5.7 (COMP/DIS/OC)
/PE6: Q1.3 (C), R1.1, R2.1, R55.1, R56.1, R265.2, R267.2, U2.5 (PE6), U5.1 (BOOT)
/PE7: R227.2, R228.1, R229.1, U2.38 (PE7)
/PE8: Q22.3 (C), R183.1, R184.1, U2.39 (PE8)
/PE9: D26.3 (K), R189.1, R190.2, U2.40 (PE9)
/PE10: Q21.3 (C), R175.1, R176.1, U2.41 (PE10)
/PE11: D10.3 (K), R181.1, R182.2, U2.42 (PE11)
/PE12: Q15.3 (C), R136.1, R137.1, U2.43 (PE12)
/PE13: R142.1, R143.2, U2.44 (PE13)
/PE14: Q23.3 (C), R191.1, R192.1, U2.45 (PE14)
/PE15: D22.3 (K), R197.1, R198.2, U2.46 (PE15)
/Prog_mode: C79.2, P1.43, R293.2, R294.2, R297.1, R298.2
/Speed_in: C78.2, P1.59, R310.2, R311.1, R312.2
/Start_req: C82.2, P1.77, R325.2, R328.1, R329.2
/TACH: C58.1, D7.2 (A), P1.8, R110.2, VT12.2 (D)
/TPS: C69.2, P1.16, R219.1, R220.2, R221.1
/Unk_Out_1: C56.1, P1.9, R94.2, VT10.2 (D)
/VBAT: C104.2, D62.2 (A), R302.1, U2.6 (VBAT)
GND: C1.2, C2.2, C3.2, C4.2, C5.1, C6.2, C7.2, C8.1, C9.1, C10.2, C11.2, C12.1, C13.2, C14.1, C15.1, C16.1, C17.1, C18.1, C19.2, C20.2, C21.2, C22.2, C23.2, C24.2, C25.2, C26.2, C27.2, C28.2, C29.2, C30.2, C31.2, C32.2, C33.2, C34.1, C35.1, C36.1, C37.1, C38.1, C39.2, C40.2, C41.2, C42.2, C43.2, C44.2, C45.2, C48.1, C49.2, C50.2, C51.2, C52.1, C53.1, C54.2, C55.2, C56.2, C57.2, C58.2, C59.2, C60.2, C61.2, C62.2, C63.2, C64.2, C65.2, C66.2, C67.2, C68.2, C69.1, C70.2, C71.2, C72.1, C73.1, C74.1, C75.1, C76.1, C77.1, C78.1, C79.1, C80.1, C81.1, C82.1, C83.1, C84.2, C85.2, C86.2, C87.2, C88.1, C89.2, C90.2, C92.2, C93.2, C94.2, C95.2, C100.2, C101.1, C102.1, C103.1, C104.1, C105.2, C106.2, C107.2, C108.2, C109.2, C110.2, C111.2, C112.2, C113.1, C114.1, C115.1, C116.1, C117.1, D2.1 (K), D5.1 (K), D6.1 (K), D9.1 (K), D10.1 (K), D15.1 (K), D21.1 (K), D22.1 (K), D24.1 (K), D25.1 (K), D26.1 (K), D27.1 (K), D29.1 (K), D30.1 (K), D31.1 (K), D32.1 (K), D33.1 (K), D37.1 (K), D38.1 (K), D39.1 (K), D40.1 (K), D41.1 (K), D42.1 (K), D43.1 (K), D45.1 (K), D47.1 (K), D48.1 (K), D50.1 (K), D51.1 (K), D52.1 (K), D53.1 (K), D54.1 (K), D55.1 (K), D56.1 (K), D58.1 (K), D59.1 (K), D60.1 (K), D61.1 (K), D62.1 (K), D64.2 (A), D66.1 (K), D67.1 (K), D68.1 (K), D69.1 (K), D70.1 (K), D71.1 (K), D72.1 (K), J1.2, P1.3, P1.61, P1.80, Q1.2 (E), Q2.2 (E), Q3.2 (E), Q5.2 (E), Q6.2 (E), Q7.2 (E), Q8.2 (E), Q9.2 (E), Q10.2 (E), Q11.2 (E), Q12.2 (E), Q13.2 (E), Q14.2 (E), Q15.2 (E), Q16.2 (E), Q17.2 (E), Q18.2 (E), Q20.2 (E), Q21.2 (E), Q22.2 (E), Q23.2 (E), Q24.3 (C), R4.2, R5.2, R6.2, R8.1, R13.2, R15.2, R22.2, R23.2, R24.2, R26.1, R30.2, R31.2, R32.2, R34.1, R41.2, R42.2, R43.2, R45.1, R50.2, R51.2, R52.2, R54.1, R57.2, R59.1, R67.2, R68.1, R70.1, R72.2, R73.2, R75.2, R91.2, R92.2, R93.2, R95.1, R99.2, R100.2, R101.2, R103.1, R107.2, R108.2, R109.2, R111.1, R115.2, R116.2, R117.2, R119.1, R123.2, R124.2, R125.2, R127.1, R131.2, R132.2, R133.2, R135.1, R139.2, R140.2, R141.2, R143.1, R147.2, R148.2, R149.2, R151.1, R152.1, R155.1, R156.1, R161.2, R162.2, R163.2, R166.1, R170.2, R171.2, R172.2, R174.1, R178.2, R179.2, R180.2, R182.1, R186.2, R187.2, R188.2, R190.1, R194.2, R195.2, R196.2, R198.1, R199.2, R200.2, R201.2, R203.2, R204.1, R205.2, R206.2, R207.2, R209.2, R210.2, R211.2, R212.2, R213.2, R215.1, R218.1, R220.1, R222.1, R223.1, R226.2, R230.2, R231.2, R233.1, R234.2, R243.2, R253.2, R255.2, R256.2, R257.2, R258.2, R259.2, R260.2, R261.2, R263.2, R266.2, R275.2, R280.2, R283.2, R296.1, R298.1, R301.1, R303.1, R305.1, R308.1, R309.1, R312.1, R314.2, R315.2, R317.2, R318.1, R321.1, R322.1, R323.1, R324.1, R329.1, R331.1, R333.1, U1.5 (VCC), U1.8 (PHASE), U2.10 (VSS), U2.20 (VSSA), U2.27 (VSS), U2.74 (VSS), U2.99 (VSS), U3.4 (V-), U4.2 (UGATE), U4.3 (GND), U5.4 (LGATE), U6.11 (V-), U7.2 (GND), U7.8 (S), U8.2 (UGATE), U8.3 (GND), U9.2 (UGATE), U9.3 (GND), VT7.3 (E), VT8.3 (E), VT9.3 (E), VT23.3 (E)
unnamed: C2.1, D66.3 (K), R9.2, R12.2, R13.1
unnamed: C5.2, R14.2, U2.14 (NRST)
unnamed: C6.1, U2.12 (PH0), X1.2
unnamed: C7.1, R202.1, X1.1
unnamed: C10.1, U2.49 (VCAP_1)
unnamed: C11.1, U2.73 (VCAP_2)
unnamed: C13.1, R304.2, X2.1
unnamed: C25.1, R152.2, R153.1, R154.1
unnamed: C27.1, D35.1 (K), U4.4 (LGATE)
unnamed: C42.1, D67.3 (K), R63.2, R66.2, R67.1
unnamed: C45.1, R245.1, R246.2
unnamed: C46.1, D73.1 (K), R247.2, R248.2, U3.2 (-)
unnamed: C46.2, D73.3 (K), R246.1, R249.2, R252.1, U3.3 (+)
unnamed: C55.1, P1.14
unnamed: C91.1, R272.1, R273.1, R276.1, U6.2 (-)
unnamed: C91.2, R277.1, R278.2, U6.1
unnamed: C94.1, R269.2, R280.1, U5.6 (FB)
unnamed: C95.1, R274.2, R275.1, U6.3 (+), U6.5 (+), U6.10 (+)
unnamed: C96.1, R279.1, U6.6 (-)
unnamed: C96.2, C97.1, R283.1, R284.2
unnamed: C97.2, R282.2, R286.1, U6.7
unnamed: C98.1, R285.1
unnamed: C99.1, R286.2
unnamed: C99.2, R287.2, R288.2, U6.9 (-)
unnamed: C100.1, D58.3 (K), R294.1, R295.2, R296.2
unnamed: C105.1, U2.8 (PC14), X2.2
unnamed: C109.1, D63.1 (K), U8.4 (LGATE), U8.5 (VCC)
unnamed: C110.1, D65.1 (K), U9.4 (LGATE)
unnamed: D1.2 (A), R11.2, R12.1
unnamed: D3.1 (K), D34.2 (A)
unnamed: D8.2 (A), R65.2, R66.1
unnamed: D15.3 (K), D23.2 (A), Q17.3 (C), R16.1, R17.1, R211.1, R212.1
unnamed: D23.1 (K), R157.1
unnamed: D28.2 (A), R16.2
unnamed: D29.3 (K), R153.2
unnamed: D34.1 (K), VT24.2 (D)
unnamed: D49.1 (K), R237.2
unnamed: D57.1 (K), R287.1, U6.12 (+)
unnamed: D57.2 (A), R288.1, R289.1
unnamed: D57.3 (K), U6.8
unnamed: Q1.1 (B), R3.1
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

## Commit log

2023-01-29 S105: some reversed schematic blocks
    [OD_2A.kicad_sch, ign_out.kicad_sch, s105.kicad_pcb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]
2023-01-29 only folder rename
    [OD_2A.kicad_sch, ign_out.kicad_sch, s105.kicad_pcb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]
2023-02-07 наименование цепей разъема
    [s105.kicad_sch, stm32.kicad_sch]
2023-02-08 разместила схожие блоки
    [OD_2A.kicad_sch, ign_out.kicad_sch, s105.kicad_pcb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]
2023-02-09 вписала в габариты платы, продолжила опознание
    [MPSNG5.kicad_sch, OD_2A_2.kicad_sch, OD_2A_3.kicad_sch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]
2023-02-10 новые модули, продолжение расположения
    [MPSNG5.kicad_sch, analog.kicad_sch, s105.kicad_pcb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]
2023-02-14 заполняем плату дальше
    [ak1sl.kicad_sch, ak1sl2.kicad_sch, analog.kicad_sch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]
2023-02-16 can, analog inputs
    [CAN.kicad_sch, LM2902.kicad_sch, analog.kicad_sch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]
2023-02-16 закончила пока что
    [LM2902.kicad_sch, MA84795A.kicad_sch, MA84795A2.kicad_sch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]
2023-02-21 #4 #5 #6 #8
    [CAN.kicad_sch, LM2902.kicad_sch, MA84795A.kicad_sch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]
